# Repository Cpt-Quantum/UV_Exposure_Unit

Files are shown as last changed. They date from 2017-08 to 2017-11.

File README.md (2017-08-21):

# UV_Exposure_Unit
A directory for my UV exposure unit with code for a PIC18F45K50, and schematics.

Due to the nature of the electronic arrangement for this project a picture will be provided of the finished project to show how it is all assembled. The boards are all quite small and were designed to be modular, none of which are particularly complicated individually. The reason I went for an active control system for this project was so that it was self timing and then would shut off, so that it does not need to be managed, as the circuit board being exposed can be quite sensitive as to how much UV exposure it recieves.

A quick note: The PIC had to be changed midway through development due to one of the ports on my PIC16F877A being damaged, this made setting the individual bits on port B clear the states of the other pins in port B. This made my LCD library non-functional since it sets the individual bits. I have now changed the project to use the PIC18F45K50, I will be updating the schematics accordingly when I get round to finishing them.

The credit for the debouncing algorithm goes to Jack Ganssle. I do recommend reading his document on button debouncing (http://www.ganssle.com/debouncing.htm) as it goes into a lot of detail behind button bounce. The algorithm is particularly well designed to be called on an interrupt to minimise load on the CPU caused by traditional methods which use __delay(...). I have not implemented it this way for this project as the load on the CPU is relatively low.

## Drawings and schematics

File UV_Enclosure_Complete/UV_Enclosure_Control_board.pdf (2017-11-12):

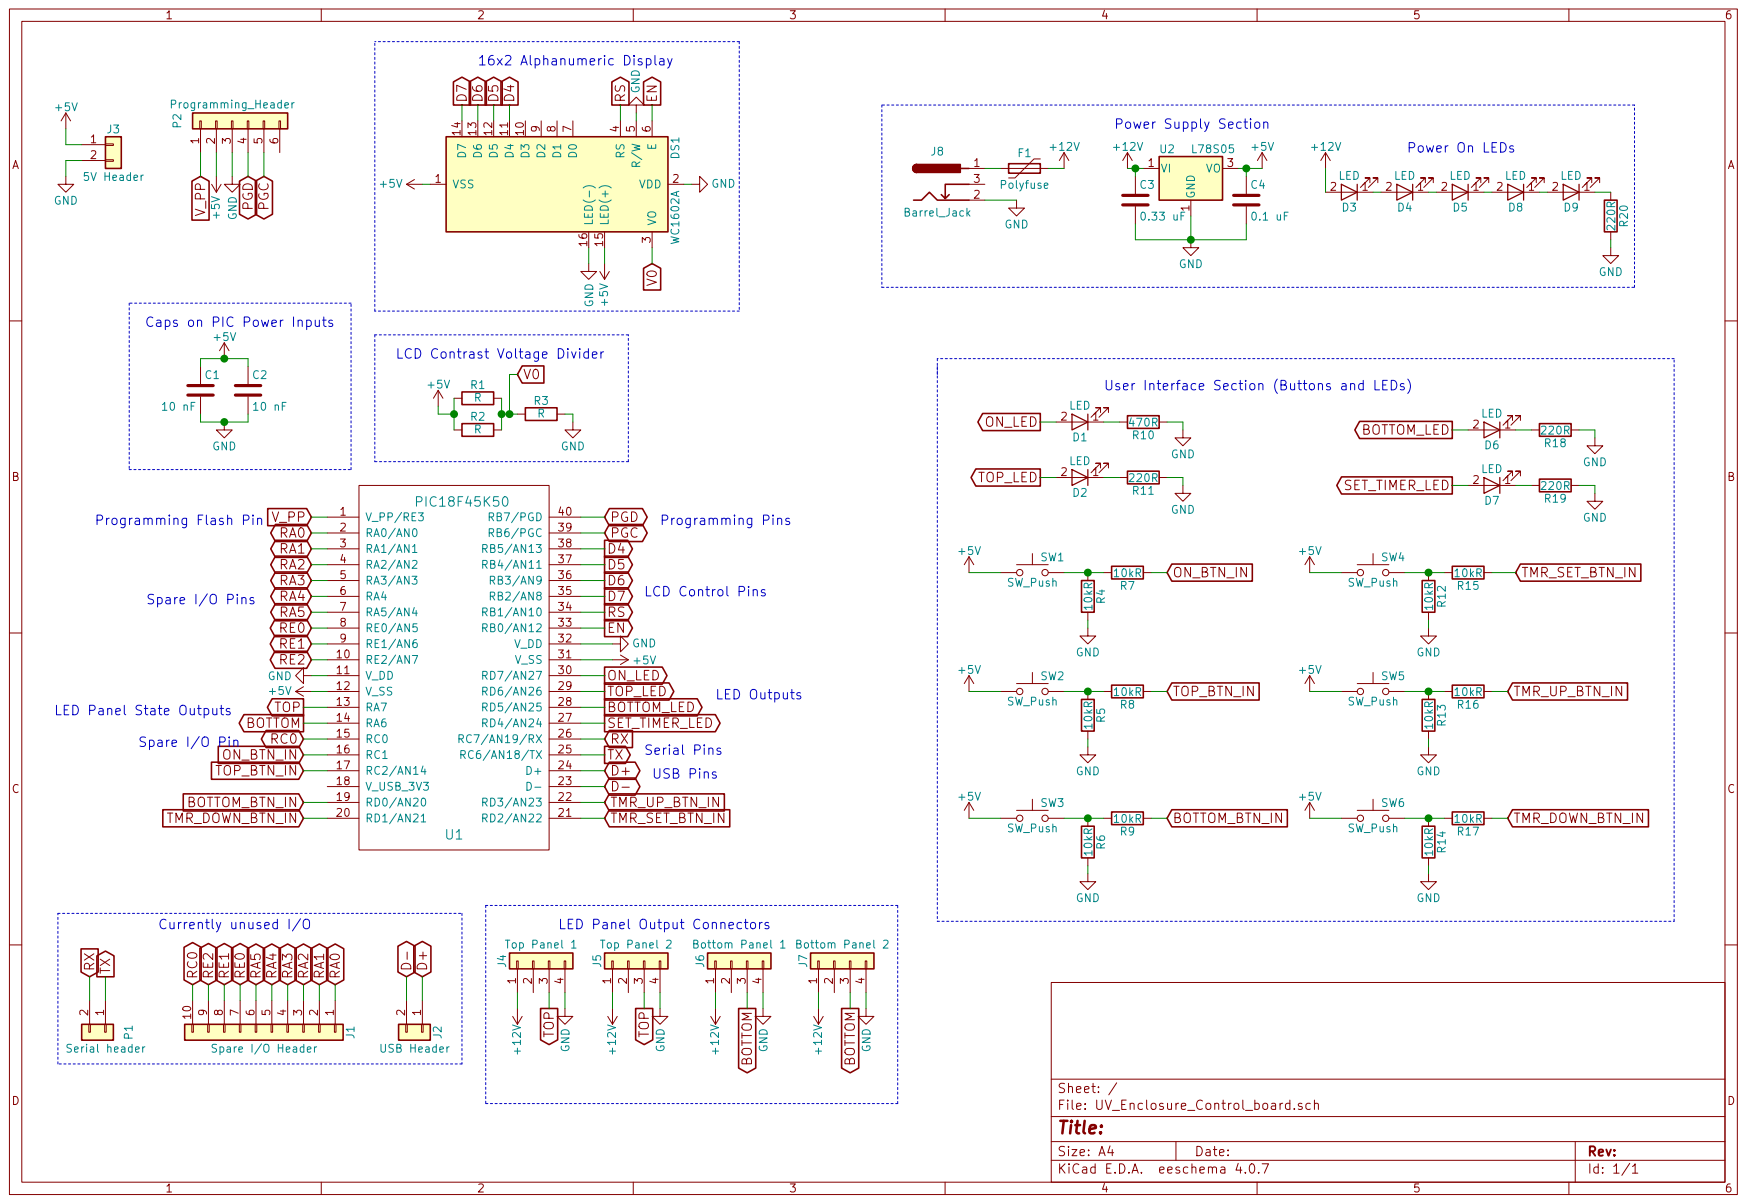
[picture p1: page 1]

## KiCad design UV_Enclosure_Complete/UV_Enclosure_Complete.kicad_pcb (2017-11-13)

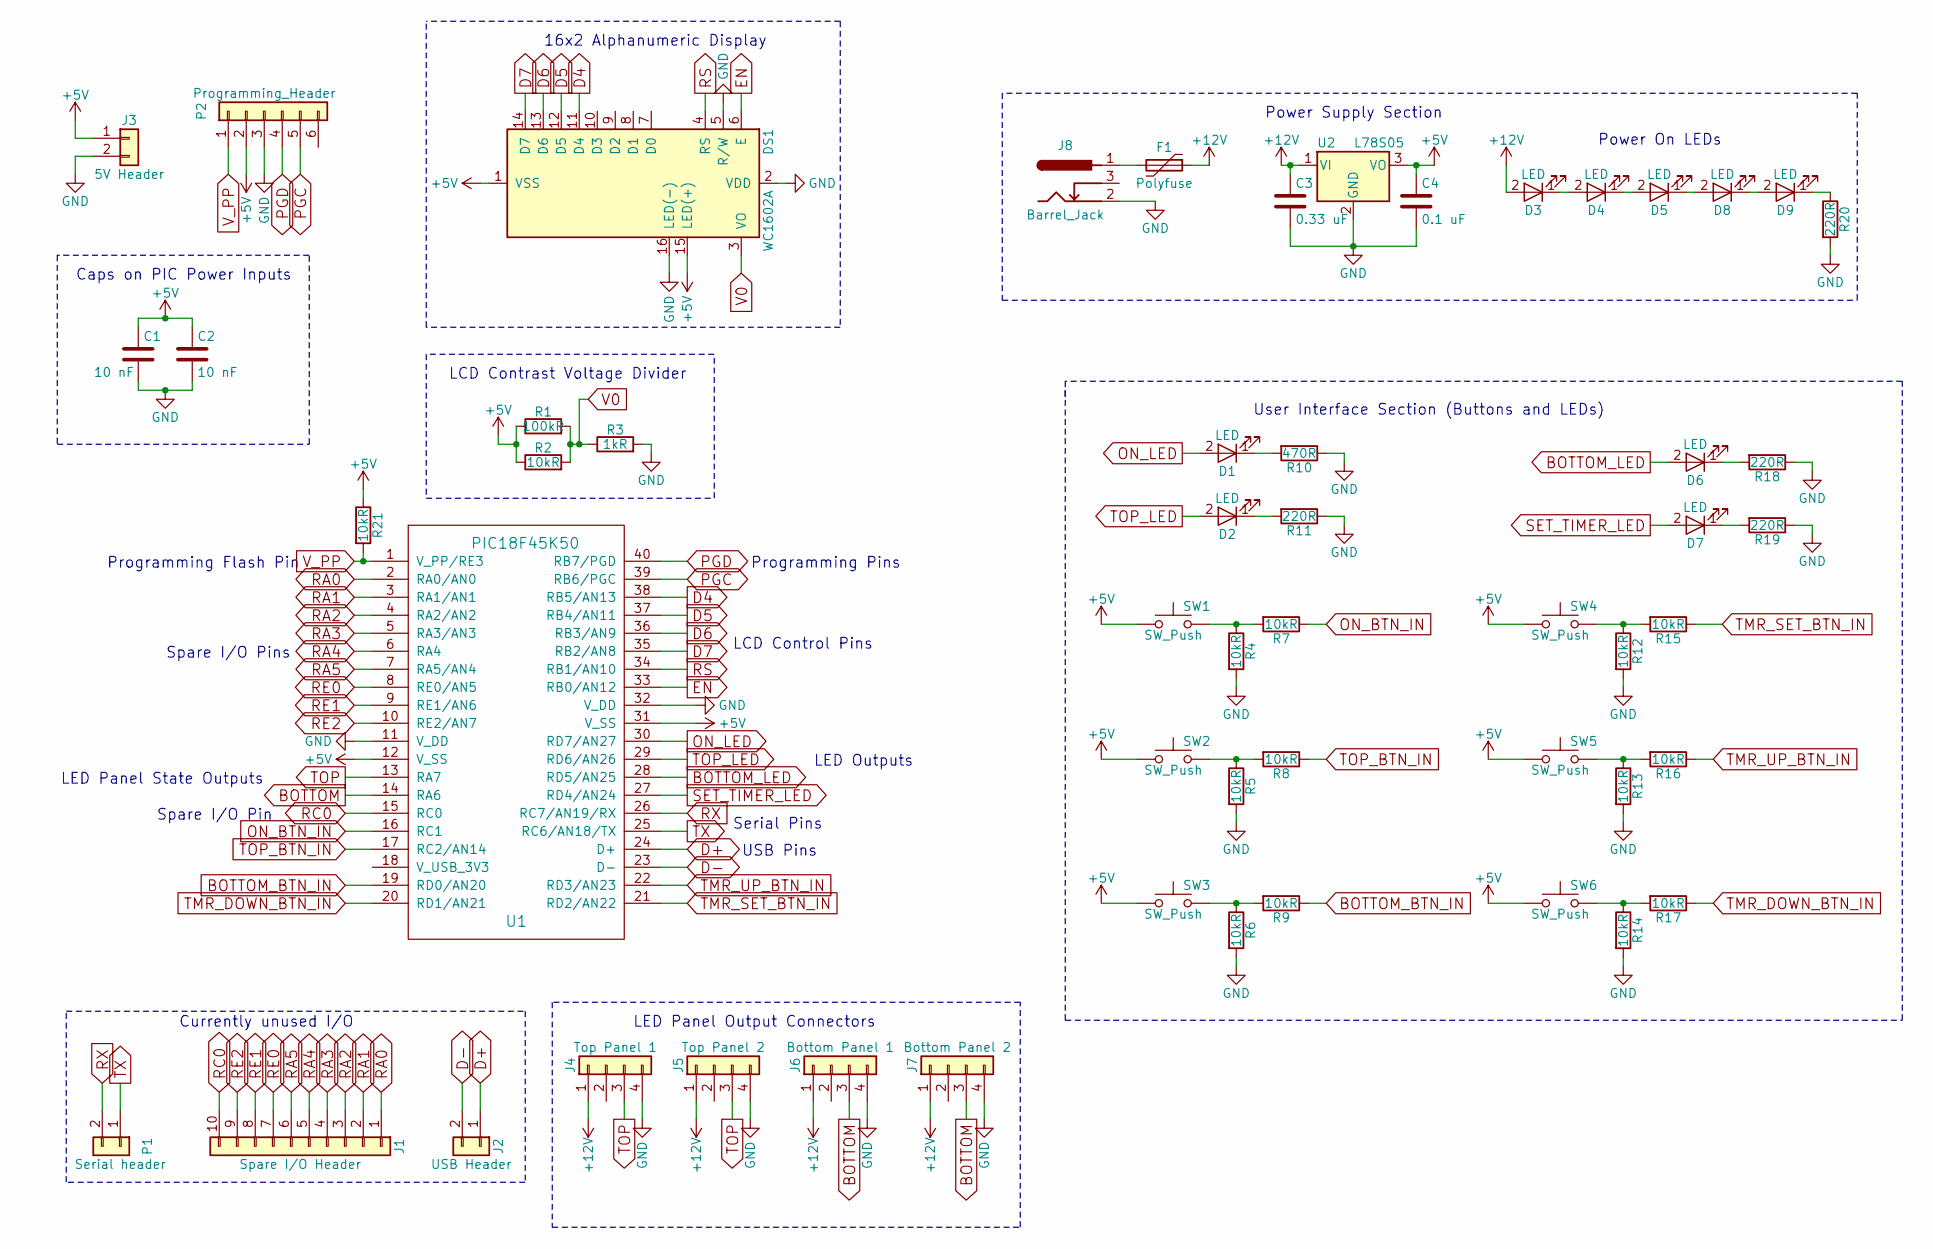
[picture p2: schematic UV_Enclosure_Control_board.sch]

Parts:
C1, C2: 10 nF; C_Disc_D3.0mm_W2.0mm_P2.50mm
C3: 0.33 uF; C_Rect_L9.0mm_W4.9mm_P7.50mm_MKT
C4: 0.1 uF; C_Rect_L9.0mm_W3.2mm_P7.50mm_MKT
D1, D2, D3, D4, D5, D6, D7, D8, D9: LED; LED_D5.0mm
DS1: WC1602A
F1: Polyfuse; Polyfuse-2A-Square-Horizontal
J1: Spare I/O Header; Pin_Header_Straight_1x10_Pitch2.54mm
J2: USB Header; Pin_Header_Straight_1x02_Pitch2.54mm
J3: 5V Header; Pin_Header_Straight_1x02_Pitch2.54mm
J4: Top Panel 1; Pin_Header_Straight_1x04_Pitch2.54mm
J5: Top Panel 2; Pin_Header_Straight_1x04_Pitch2.54mm
J6: Bottom Panel 1; Pin_Header_Straight_1x04_Pitch2.54mm
J7: Bottom Panel 2; Pin_Header_Straight_1x04_Pitch2.54mm
J8: Barrel_Jack; BARREL_JACK
P1: Serial header; Pin_Header_Straight_1x02_Pitch2.54mm
P2: Programming_Header; Pin_Header_Straight_1x06_Pitch2.54mm
R1: 100kR; R_Axial_DIN0309_L9.0mm_D3.2mm_P12.70mm_Horizontal
R2, R4, R5, R6, R7, R8, R9, R12, R13, R14, R15, R16, R17, R21: 10kR; R_Axial_DIN0309_L9.0mm_D3.2mm_P12.70mm_Horizontal
R3: 1kR; R_Axial_DIN0309_L9.0mm_D3.2mm_P12.70mm_Horizontal
R10: 470R; R_Axial_DIN0309_L9.0mm_D3.2mm_P12.70mm_Horizontal
R11, R18, R19, R20: 220R; R_Axial_DIN0309_L9.0mm_D3.2mm_P12.70mm_Horizontal
SW1, SW2, SW3, SW4, SW5, SW6: SW_Push; SW_Tactile_Straight_KSA0Axx1LFTR
U1: PIC18F45K50; DIP-40_0
U2: L78S05; TO-220-3_Horizontal

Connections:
+5V: C1.1, C2.1, C4.1, DS1.1 (VSS), DS1.15 (LED(+)), J3.1, P2.2, R1.1, R2.1, R21.1, SW1.1, SW2.1, SW3.1, SW4.1, SW5.1, SW6.1, U1.12 (V_SS), U1.31 (V_SS), U2.3 (VO)
+12V: C3.1, D3.2 (A), F1.1, J4.1, J5.1, J6.1, J7.1, U2.1 (VI)
BOTTOM: J6.3, J7.3, U1.14 (RA6)
BOTTOM_BTN_IN: R9.1, U1.19 (RD0/AN20)
BOTTOM_LED: D6.2 (A), U1.28 (RD5/AN25)
D4: DS1.11 (D4), U1.38 (RB5/AN13)
D5: DS1.12 (D5), U1.37 (RB4/AN11)
D6: DS1.13 (D6), U1.36 (RB3/AN9)
D7: DS1.14 (D7), U1.35 (RB2/AN8)
D+: J2.1, U1.24 (D+)
D-: J2.2, U1.23 (D-)
EN: DS1.6 (E), U1.33 (RB0/AN12)
GND: C1.2, C2.2, C3.2, C4.2, DS1.2 (VDD), DS1.5 (R/W), DS1.16 (LED(-)), J3.2, J4.4, J5.4, J6.4, J7.4, J8.2, P2.3, R3.2, R4.2, R5.2, R6.2, R10.1, R11.1, R12.2, R13.2, R14.2, R18.1, R19.1, R20.2, U1.11 (V_DD), U1.32 (V_DD), U2.2 (GND)
unnamed: D1.1 (K), R10.2
unnamed: D2.1 (K), R11.2
unnamed: D3.1 (K), D4.2 (A)
unnamed: D4.1 (K), D5.2 (A)
unnamed: D5.1 (K), D8.2 (A)
unnamed: D6.1 (K), R18.2
unnamed: D7.1 (K), R19.2
unnamed: D8.1 (K), D9.2 (A)
unnamed: D9.1 (K), R20.1
unnamed: F1.2, J8.1
unnamed: R4.1, R7.2, SW1.2
unnamed: R5.1, R8.2, SW2.2
unnamed: R6.1, R9.2, SW3.2
unnamed: R12.1, R15.2, SW4.2
unnamed: R13.1, R16.2, SW5.2
unnamed: R14.1, R17.2, SW6.2
ON_BTN_IN: R7.1, U1.16 (RC1)
ON_LED: D1.2 (A), U1.30 (RD7/AN27)
PGC: P2.5, U1.39 (RB6/PGC)
PGD: P2.4, U1.40 (RB7/PGD)
RA0: J1.1, U1.2 (RA0/AN0)
RA1: J1.2, U1.3 (RA1/AN1)
RA2: J1.3, U1.4 (RA2/AN2)
RA3: J1.4, U1.5 (RA3/AN3)
RA4: J1.5, U1.6 (RA4)
RA5: J1.6, U1.7 (RA5/AN4)
RC0: J1.10, U1.15 (RC0)
RE0: J1.7, U1.8 (RE0/AN5)
RE1: J1.8, U1.9 (RE1/AN6)
RE2: J1.9, U1.10 (RE2/AN7)
RS: DS1.4 (RS), U1.34 (RB1/AN10)
RX: P1.2, U1.26 (RC7/AN19/RX)
SET_TIMER_LED: D7.2 (A), U1.27 (RD4/AN24)
TMR_DOWN_BTN_IN: R17.1, U1.20 (RD1/AN21)
TMR_SET_BTN_IN: R15.1, U1.21 (RD2/AN22)
TMR_UP_BTN_IN: R16.1, U1.22 (RD3/AN23)
TOP: J4.3, J5.3, U1.13 (RA7)
TOP_BTN_IN: R8.1, U1.17 (RC2/AN14)
TOP_LED: D2.2 (A), U1.29 (RD6/AN26)
TX: P1.1, U1.25 (RC6/AN18/TX)
V0: DS1.3 (VO), R1.2, R2.2, R3.1
V_PP: P2.1, R21.2, U1.1 (V_PP/RE3)

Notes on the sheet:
Programming Pins
LCD Control Pins
LED Outputs
Serial Pins
USB Pins
Spare I/O Pins
Programming Flash Pin
LED Panel State Outputs
Spare I/O Pin
Caps on PIC Power Inputs
Currently unused I/O
LED Panel Output Connectors
Power On LEDs
Power Supply Section
User Interface Section (Buttons and LEDs)
LCD Contrast Voltage Divider
16x2 Alphanumeric Display

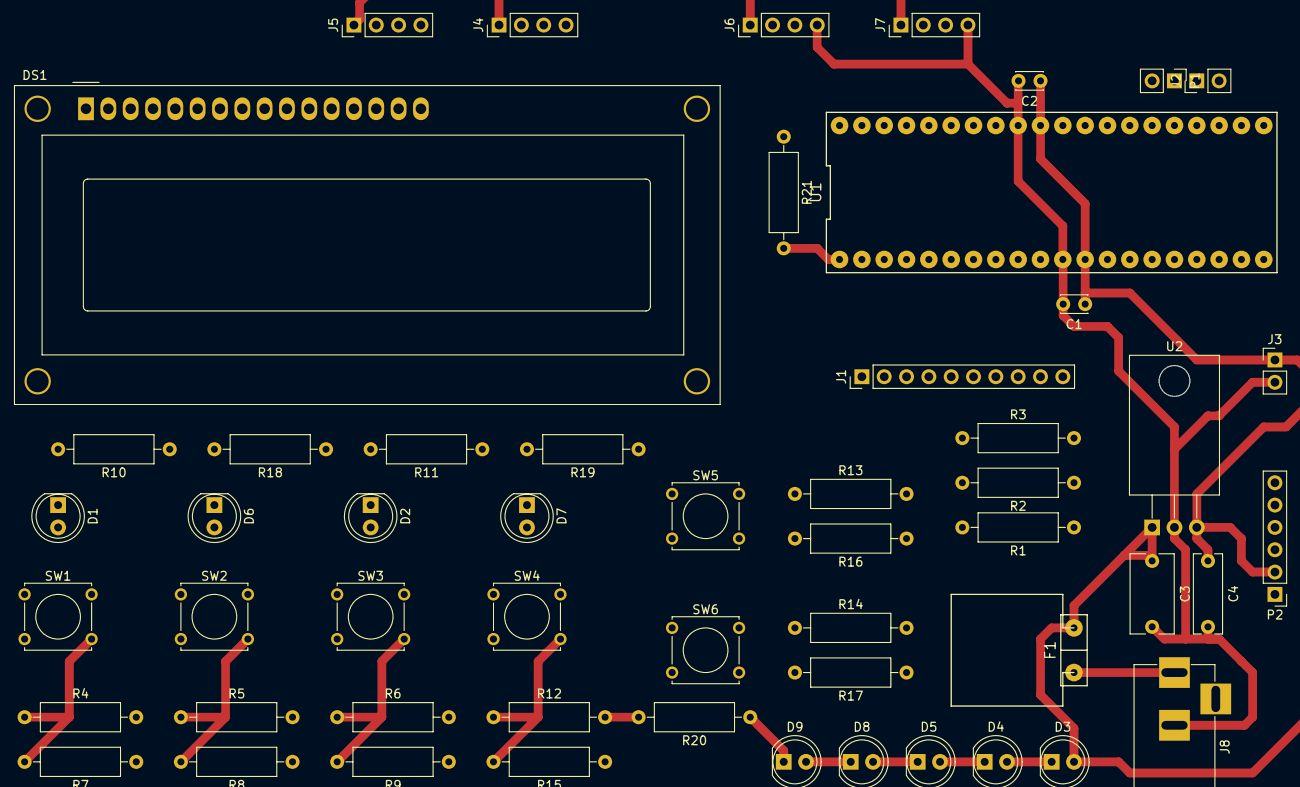
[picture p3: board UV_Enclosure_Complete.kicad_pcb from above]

Board: 2 copper layers, 54 parts (0 on the bottom side), 55 nets.

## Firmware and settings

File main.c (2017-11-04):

 /*
 * File:   main.C
 * Author: Connor
 *
 * Created on August 12, 2017, 5:21 PM
 */

/*************************************************/

// 'C' source line config statements

#include <xc.h>

/* PIC18F45K50 Configuration Bit Settings */
// #pragma config statements should precede project file includes.
// Use project enums instead of #define for ON and OFF.

// CONFIG1L
#pragma config PLLSEL = PLL4X   // PLL Selection (4x clock multiplier)
#pragma config CFGPLLEN = OFF   // PLL Enable Configuration bit (PLL Disabled (firmware controlled))
#pragma config CPUDIV = NOCLKDIV// CPU System Clock Postscaler (CPU uses system clock (no divide))
#pragma config LS48MHZ = SYS24X4// Low Speed USB mode with 48 MHz system clock (System clock at 24 MHz, USB clock divider is set to 4)

// CONFIG1H
#pragma config FOSC = INTOSCIO  // Oscillator Selection (Internal oscillator)
#pragma config PCLKEN = ON      // Primary Oscillator Shutdown (Primary oscillator enabled)
#pragma config FCMEN = OFF      // Fail-Safe Clock Monitor (Fail-Safe Clock Monitor disabled)
#pragma config IESO = OFF       // Internal/External Oscillator Switchover (Oscillator Switchover mode disabled)

// CONFIG2L
#pragma config nPWRTEN = OFF    // Power-up Timer Enable (Power up timer disabled)
#pragma config BOREN = SBORDIS  // Brown-out Reset Enable (BOR enabled in hardware (SBOREN is ignored))
#pragma config BORV = 190       // Brown-out Reset Voltage (BOR set to 1.9V nominal)
#pragma config nLPBOR = OFF     // Low-Power Brown-out Reset (Low-Power Brown-out Reset disabled)

// CONFIG2H
#pragma config WDTEN = ON       // Watchdog Timer Enable bits (WDT enabled in hardware (SWDTEN ignored))
#pragma config WDTPS = 32768    // Watchdog Timer Postscaler (1:32768)

// CONFIG3H
#pragma config CCP2MX = RC1     // CCP2 MUX bit (CCP2 input/output is multiplexed with RC1)
#pragma config PBADEN = OFF     // PORTB A/D Enable bit (PORTB<5:0> pins are configured as digital I/O on Reset)
#pragma config T3CMX = RC0      // Timer3 Clock Input MUX bit (T3CKI function is on RC0)
#pragma config SDOMX = RB3      // SDO Output MUX bit (SDO function is on RB3)
#pragma config MCLRE = ON       // Master Clear Reset Pin Enable (MCLR pin enabled; RE3 input disabled)

// CONFIG4L
#pragma config STVREN = ON      // Stack Full/Underflow Reset (Stack full/underflow will cause Reset)
#pragma config LVP = OFF        // Single-Supply ICSP Enable bit (Single-Supply ICSP disabled)
#pragma config ICPRT = OFF      // Dedicated In-Circuit Debug/Programming Port Enable (ICPORT disabled)
#pragma config XINST = OFF      // Extended Instruction Set Enable bit (Instruction set extension and Indexed Addressing mode disabled)

// CONFIG5L
#pragma config CP0 = OFF        // Block 0 Code Protect (Block 0 is not code-protected)
#pragma config CP1 = OFF        // Block 1 Code Protect (Block 1 is not code-protected)
#pragma config CP2 = OFF        // Block 2 Code Protect (Block 2 is not code-protected)
#pragma config CP3 = OFF        // Block 3 Code Protect (Block 3 is not code-protected)

// CONFIG5H
#pragma config CPB = OFF        // Boot Block Code Protect (Boot block is not code-protected)
#pragma config CPD = OFF        // Data EEPROM Code Protect (Data EEPROM is not code-protected)

// CONFIG6L
#pragma config WRT0 = OFF       // Block 0 Write Protect (Block 0 (0800-1FFFh) is not write-protected)
#pragma config WRT1 = OFF       // Block 1 Write Protect (Block 1 (2000-3FFFh) is not write-protected)
#pragma config WRT2 = OFF       // Block 2 Write Protect (Block 2 (04000-5FFFh) is not write-protected)
#pragma config WRT3 = OFF       // Block 3 Write Protect (Block 3 (06000-7FFFh) is not write-protected)

// CONFIG6H
#pragma config WRTC = OFF       // Configuration Registers Write Protect (Configuration registers (300000-3000FFh) are not write-protected)
#pragma config WRTB = OFF       // Boot Block Write Protect (Boot block (0000-7FFh) is not write-protected)
#pragma config WRTD = OFF       // Data EEPROM Write Protect (Data EEPROM is not write-protected)

// CONFIG7L
#pragma config EBTR0 = OFF      // Block 0 Table Read Protect (Block 0 is not protected from table reads executed in other blocks)
#pragma config EBTR1 = OFF      // Block 1 Table Read Protect (Block 1 is not protected from table reads executed in other blocks)
#pragma config EBTR2 = OFF      // Block 2 Table Read Protect (Block 2 is not protected from table reads executed in other blocks)
#pragma config EBTR3 = OFF      // Block 3 Table Read Protect (Block 3 is not protected from table reads executed in other blocks)

// CONFIG7H
#pragma config EBTRB = OFF      // Boot Block Table Read Protect (Boot block is not protected from table reads executed in other blocks)

/* End of PIC18F45K50 Configuration Bit Settings */
/*************************************************/

#include <stdint.h>
#include "debounce.h"
#include "LCD.h"
#include "general.h"

//Define oscillator frequency for delay function use
#define _XTAL_FREQ 1000000

//Define the pins for the MOSFET switches
#define TOP_STATE           LATAbits.LATA7
#define BOTTOM_STATE        LATAbits.LATA6

//Global variable to save the set on_time between runs
unsigned long g_on_time = 300;

void main(void) {
    //Turn off comparitors
    CM1CON0 = 0x07;
    CM2CON0 = 0x07;

    //Turn off analogue functions to appropriate pins
    ANSELA = 0x00;
    ANSELC = 0x00;
    ANSELD = 0x00;
    ANSELE = 0x00;

    //Initialise the ports as needed
    debounce_initialise();
    TRISB = 0x00;

    //Initialise LCD
    LCD_Initialise(1, 0, 0, 0);

    //Move to start position on the LCD
    LCD_Cursor_Position(1, 1);

    //Start while loop to keep the program looping forever    
    while (1) {
        
        Reset_States();
        LCD_Clear();
        Set_On_Time(g_on_time);

        //Initialise states for the LED panels
        TOP_STATE = 0;
        BOTTOM_STATE = 0;

        //Button read state:
        //This is the initial state, the PIC waits for the user to push the ON_BTN
        // to put the PIC into the on state. This is also the state to set the timer
        // and which LED panels (top or bottom) to turn on.
        while (ON_State() == 0) {
            //Write "Select states" to LCD
            LCD_Cursor_Position(1, 1);
            LCD_Write_String("Select states", 13);
            //Display current set time on LCD
            LCD_Cursor_Position(1,2);
            LCD_Write_String("Timer:",6);
            //Now display current time that the system is set to run
            LCD_Cursor_Position(7,2);
            char ctime[] = "00m00s";
            LCD_Write_String(Time_mmss(ctime,On_Time()),6);
            //Clear last 4 characters on the second row
            LCD_Write_String("    ",4);
            
            //Use an internal for loop to reduce the effect of the LCD functions'
            // wait times on the debounce functionality.
            for (int i = 0; i < 100; i++) {
                //Read the buttons and set the states accordingly
                debounce_ON_BTN();
                debounce_TOP_BTN();
                debounce_BOTTOM_BTN();
                debounce_TMR_SET_BTN();

                //If the timer set button has been activated, read the button states for
                // the up/down user inputs and wait until user presses the timer set 
                //button again.
                while (TMR_SET_State() == 1) {
                    //Prompt user to set time on the LCD and display current time that 
                    // the LED panels are set to be on for.
                    LCD_Cursor_Position(1,2);
                    LCD_Write_String("Set timer:", 10);
                    LCD_Write_String(Time_mmss(ctime,On_Time()),6);
                    
                    //For loop to reduce effect of LCD functions on debouncing
                    for(int i = 0; i<100; i++){
                        //Set timer with buttons
                        debounce_TMR_DOWN_BTN();
                        debounce_TMR_UP_BTN();
                        debounce_TMR_SET_BTN();
                    }
                }
                __delay_ms(1);
            }
        }//End of button read state
        

        //On state:
        //This is the state where the PIC switches on the LED panels and counts up
        // to the set timer amount and then switches off the panels. It then goes
        //back in to the button read state. The system can also exit this state if
        // the user presses the on/off button
        
        //Firstly, store the current on_time so it is remembered after the timer 
        // expires.
        g_on_time = On_Time();
        
        //Switch on the MOSFETs according to the user set state (held in the LED 
        //states)
        TOP_STATE = TOP_State();
        BOTTOM_STATE = BOTTOM_State();
        
        LCD_Clear();
        LCD_Cursor_Position(1,1);
        LCD_Write_String("LED panels on!",14);
        LCD_Cursor_Position(1,2);
        LCD_Write_String("Time left:", 10);
        LCD_Cursor_Position(11,2);
        char ctime[] = "00m00s";
        LCD_Write_String(Time_mmss(ctime,On_Time()),6);
                
        //Begin counter
        while (On_Time()>=1){
            if (ON_State() == 0) break;
            for(int i = 0; i<1000; i++){
                debounce_ON_BTN();
                __delay_ms(1);
            }
            if (ON_State() == 0) break;
            Set_On_Time(On_Time()-1);
            //Update time left on the LCD
            LCD_Cursor_Position(11,2);
            LCD_Write_String(Time_mmss(ctime,On_Time()),6);     
        }

    }//End program while loop
}//End of main

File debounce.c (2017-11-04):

/*
 * File:   debounce.c
 * Author: Connor
 *
 * Created on August 12, 2017, 6:03 PM
 * 
 * This file handles the user inputs and states set by the user
 */


#include <xc.h>
#include "debounce.h"
#include <stdint.h>

//Define the pins for the buttons
#define ON_BTN_IN           PORTCbits.RC1    
#define TOP_BTN_IN          PORTCbits.RC2
#define BOTTOM_BTN_IN       PORTDbits.RD0
#define TMR_DOWN_BTN_IN     PORTDbits.RD1
#define TMR_UP_BTN_IN       PORTDbits.RD3
#define TMR_SET_BTN_IN      PORTDbits.RD2

//Define the pins for the status LEDs
#define ON_LED              LATDbits.LATD7
#define TOP_LED             LATDbits.LATD6
#define BOTTOM_LED          LATDbits.LATD5
#define SET_TIMER_LED       LATDbits.LATD4


//Variable to store the on time in seconds - default of 30 seconds
unsigned long on_time = 30;

//Debounce functions. Credit goes to Jack Ganssle for the original algorithm
//This function is called on a regular interrupt inside the latching function

void debounce_ON_BTN(){
    static uint16_t State1;              //Current debounce status
    State1 = (State1<<1 | !ON_BTN_IN | 0xE000);
    if(State1 == 0xF000){
        ON_LED=!ON_LED;
        State1 = 0x0000;
    }
}

void debounce_TOP_BTN(){
    static uint16_t State2;              //Current debounce status
    State2 = (State2<<1 | !TOP_BTN_IN | 0xE000);
    if(State2 == 0xF000){
        TOP_LED=!TOP_LED;
        State2 = 0x0000;
    }
}

void debounce_BOTTOM_BTN(){
    static uint16_t State3;              //Current debounce status
    State3 = (State3<<1 | !BOTTOM_BTN_IN | 0xE000);
    if(State3 == 0xF000){
        BOTTOM_LED=!BOTTOM_LED;
        State3 = 0x0000;
    }
}

void debounce_TMR_DOWN_BTN(){
    static uint16_t State4;              //Current debounce status
    State4 = (State4<<1 | !TMR_DOWN_BTN_IN | 0xE000);
    if(State4 == 0xF000){
        on_time = on_time - 10;
        State4 = 0x0000;
    }
}

void debounce_TMR_UP_BTN(){
    static uint16_t State5;              //Current debounce status
    State5 = (State5<<1 | !TMR_UP_BTN_IN | 0xE000);
    if(State5 == 0xF000){
        on_time = on_time + 10;
        State5 = 0x0000;
    }
}

void debounce_TMR_SET_BTN(){
    static uint16_t State6;              //Current debounce status
    State6 = (State6<<1 | !TMR_SET_BTN_IN | 0xE000);
    if(State6 == 0xF000){
        SET_TIMER_LED=!SET_TIMER_LED;
        State6 = 0x0000;
    }
}

//Initialisation function to set all outputs to zero
void debounce_initialise(){
    //Initialise relevant ports
    TRISD = 0x0F;
    TRISC = 0x0F;
    
    //Initialise the pins set as outputs to safe values
    ON_LED = 0;
    TOP_LED = 0;
    BOTTOM_LED = 0;
    SET_TIMER_LED = 0;
}

//State handling functions
uint8_t ON_State(){return ON_LED;}
uint8_t TMR_SET_State(){return SET_TIMER_LED;}
uint8_t TOP_State(){return TOP_LED;}
uint8_t BOTTOM_State(){return BOTTOM_LED;}

//Function to reset all states
void Reset_States(){
    ON_LED = SET_TIMER_LED = TOP_LED = BOTTOM_LED = 0;
}

//Function to return the set on_time
unsigned long On_Time(){return on_time;}

//Function to set the on time
void Set_On_Time(unsigned long set_on_time){on_time = set_on_time;}

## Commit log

2017-08-21 Changed header files
    Changed header files to work with the new PIC. Also separated the button inputs and LED output handling into its own header.
2017-08-21 New main
    Changed main c file to be main.c, updated code to probe and test the LCD and debounce headers.
2017-08-22 Added for loop to initialise state
    Added a for loop to the initialise state to reduce the effect of the __delay_ms waits present in the LCD code. The for loop basically calls 100 debounce cycles before updating the display, leading to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
2017-08-30 Added general functions header
    Added a general functions header to handle conversion between the time stored in seconds and the display the time in minutes/seconds on the LCD. These functions have also been implemented in main.c.
    As a side note, I also added a set function for the on_time variable to allow for a global variable to store the user set on time between runs of the software (not saved between power cycles though).
2017-08-30 Revert "Revert "Added general functions header""
    This reverts commit 4643dd338e4f4dd2f26b40bc4247b835f92d1ce2, reversing
    changes made to 7d9e59b4d017d6996570e25517b1465593b57b1f.
    [debounce.c, main.c]
2017-08-30 Updated schematic for control board
    Updated the schematic for the new control board with new PIC (PIC18F45K50). This was changed due to the original PIC having non-functioning pins on PORTB.
    [UV_Enclosure_PIC_board.sch]
2017-11-04 Change time variables from int to unsigned long
    The time variables have been switched from uint16_t to unsigned long which allows a much larger maximum time.
2017-11-11 Created the complete control board schematic. This superceds the other schematics.
    [UV_Enclosure_Complete.kicad_pcb, UV_Enclosure_Control_board.sch]
2017-11-11 Re-organised the repositories relating to the schematic folders, this is due to the consolidation of all schematic information into one schematic sheet.
    [UV_Enclosure.kicad_pcb, UV_Enclosure.sch, UV_Enclosure_Complete.kicad_pcb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]
2017-11-11 Changed LCD header to an LCD component.
    [UV_Enclosure_Control_board.sch]
2017-11-12 Added 5V header just in case any future additions require it.
    [UV_Enclosure_Control_board.sch]
2017-11-13 Started board layout: Finished initial component layout.
    [UV_Enclosure_Complete.kicad_pcb]
2017-11-13 Added pull up resistor on V_PP and started routing traces.
    [UV_Enclosure_Complete.kicad_pcb, UV_Enclosure_Control_board.sch]
